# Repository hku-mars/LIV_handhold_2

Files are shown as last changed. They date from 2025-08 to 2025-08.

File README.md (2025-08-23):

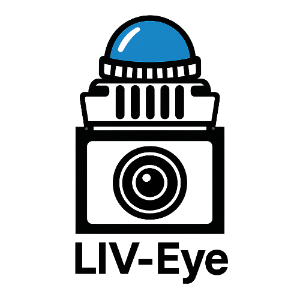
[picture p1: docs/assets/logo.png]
LIV-eye logo

<h1>LIV-Eye: A Low-Cost LiDAR-Inertial-Visual Fusion 3D Sensor for Robotics and Embodied AI <a href="./README_zh.md">[中文]</a></h1>

<p align="center">



</p>

---

## Table of Contents
- [Highlights](#highlights)
- [Repository Structure](#repository-structure)
- [Bill of Materials (BOM)](#bill-of-materials-bom)
- [Assembly](#assembly)
- [Wiring](#wiring)
- [Driver Installation and Run](#driver-installation-and-run)
- [LiDAR-Camera Joint Calibration](#lidar-camera-joint-calibration)
- [Running FAST-LIVO2](#running-fast-livo2)
- [Platform Adaptability](#platform-adaptability)
- [Acknowledgements](#acknowledgements)
- [License](#license)

---

## Highlights
> **One sentence summary**: A ~¥5000 (≈ $700) fully open-source hardware/software LiDAR-Inertial-Visual fusion perception kit. ⚙️ Easy assembly, no soldering, one-click reproducibility. 🐳 Supports ROS1/ROS2 and Docker, 🧭 full calibration workflow (intrinsic/extrinsic/time sync), 🧰 compatible with FAST-LIVO2 algorithms, and delivers colored point cloud and odometry results in just 5 minutes.

---

## Repository Structure
```text
├── FAST-LIVO2-Mid360-Config - The configuration and launch files of FAST-LIVO2 for the Mid-360 LiDAR
├── liv_eye_cad - Solidworks files for LIV-Eye
├── livox_ros_driver2 - Livox LiDAR ROS driver
├── mvs_ros_driver - Hikvision Camera ROS driver
└── README.md - Project homepage
└── ...
```

---

## Bill of Materials (BOM)

> Target total cost: ≈ ¥5,000 (≈ $700, subject to actual purchase)

| Category | Model/Name | Reference Price | Image |
|---|---|---|---|
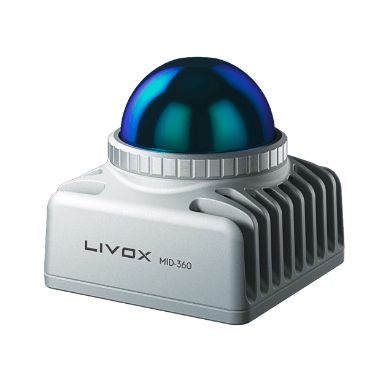
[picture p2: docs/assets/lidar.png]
MID-360
| LiDAR | [Livox Mid-360](https://www.livoxtech.com/cn/mid-360) | ¥3999 (≈ $560) |  |
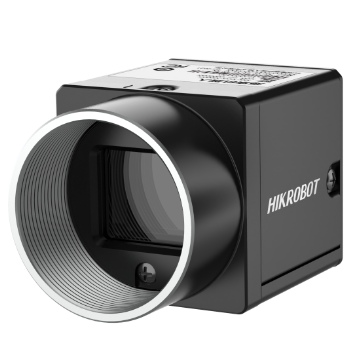
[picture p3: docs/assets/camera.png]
Camera
| Camera | [Hikvision MV-CU013-A0UC](https://www.hikrobotics.com/cn/machinevision/productdetail/?id=12628) | ¥700 (≈ $100) |  |
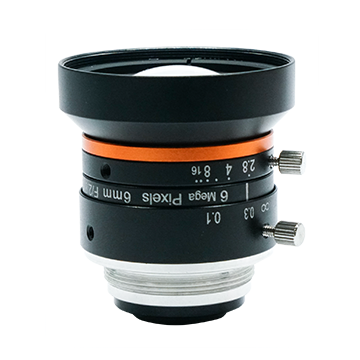
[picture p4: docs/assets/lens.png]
Lens
| Lens | [Hikvision MVL-HF0628M-6MPE](https://www.hikrobotics.com/en/machinevision/productdetail/?id=4871) | ¥150 (≈ $20) |  |
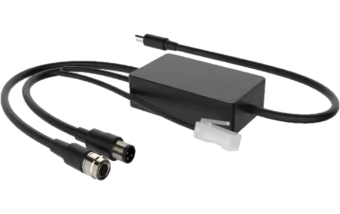
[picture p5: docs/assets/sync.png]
Sync
| Wire | [LiDAR-Camera Hardware Synchronizer](https://item.taobao.com/item.htm?id=842691502949) | ¥500 (≈ $70) |  |
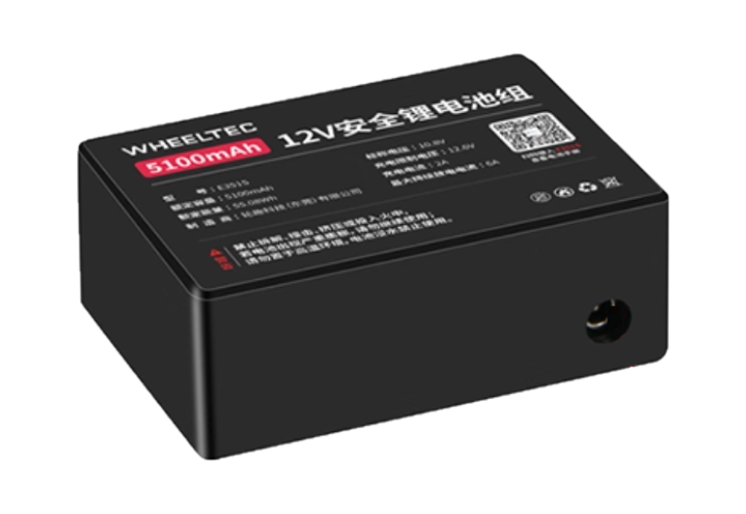
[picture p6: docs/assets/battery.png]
Battery
| Battery  | [12V DC Battery](https://detail.tmall.com/item.htm?id=657166348854) | ¥99 (≈ $15) |  |

---

## Assembly

Solidworks CAD files are provided in [liv_eye_cad](./liv_eye_cad).  
You can download and use them for 3D printing and assembly:

<p align="center">
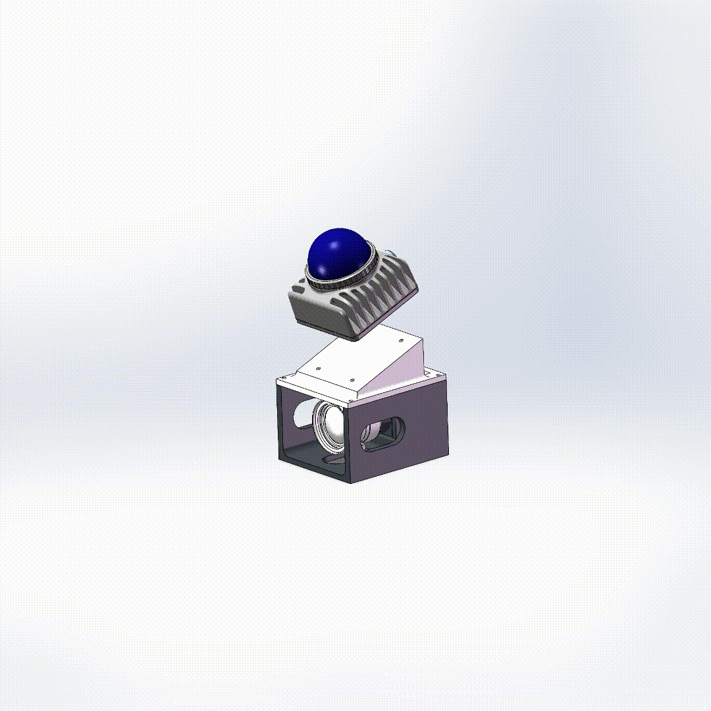
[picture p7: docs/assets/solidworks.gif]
Solidworks
  
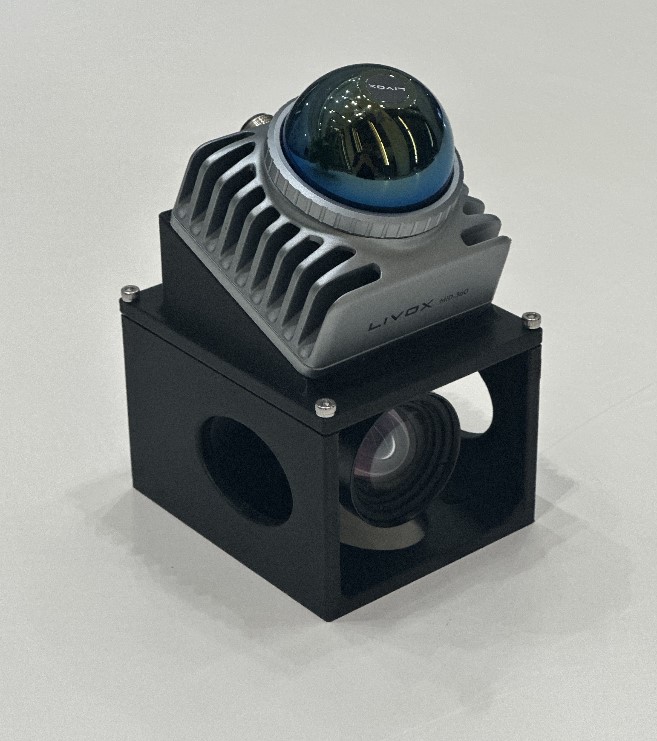
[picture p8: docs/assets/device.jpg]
Device
  
</p>

---

## Wiring

The diagram below shows the complete wiring of **LIV-Eye**, in just six steps:

<p align="center">
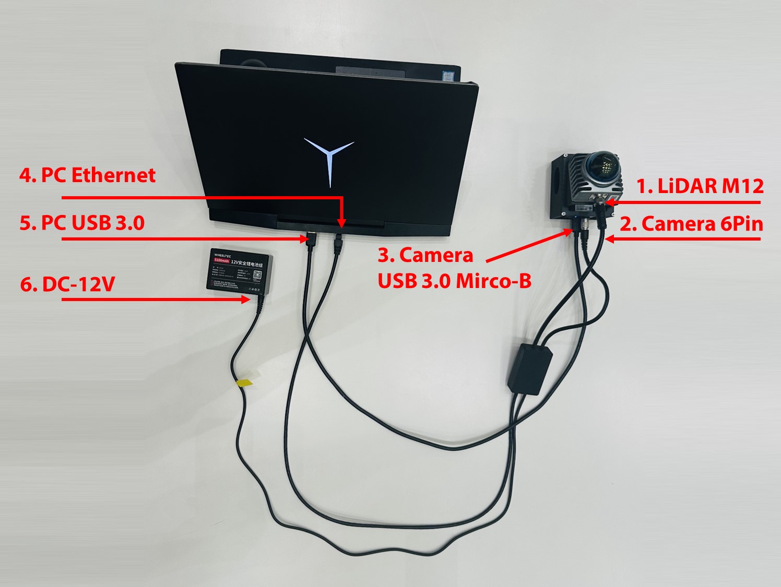
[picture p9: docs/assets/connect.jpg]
Wiring diagram
  
</p>

> **Note**  
> If you do not need to use the LiDAR-Camera hardware synchronizer, please refer to the connection method and STM32 hardware synchronization solution in [LIV_handhold](https://github.com/xuankuzcr/LIV_handhold).

---

## Driver Installation and Run

1. Download and install [MVS](https://connecthkuhk-my.sharepoint.com/:u:/g/personal/zhengcr_connect_hku_hk/Ed0Xq17d6udNqYn4vkR71bQBFz0z6_Kru3cz1gD95FIgrQ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) and [Livox-SDK2](https://github.com/Livox-SDK/Livox-SDK2). Set the camera to *trigger mode* in MVS.

2. Install the camera ROS driver [mvs_ros_driver](./mvs_ros_driver) and launch in trigger mode:
```bash
roslaunch mvs_ros_driver mvs_camera_trigger.launch 
```

3. Install and launch the LiDAR ROS driver [livox_ros_driver2](./livox_ros_driver2):
```bash
roslaunch livox_ros_driver2 msg_MID360.launch
```

4. Record sensor data:
```bash
rosbag record /livox/lidar /livox/imu /left_camera/image
```

> **Note**  
> The [mvs_ros_driver](./mvs_ros_driver) and [livox_ros_driver2](./livox_ros_driver2) are the same as those in [LIV_handhold](https://github.com/xuankuzcr/LIV_handhold), and include modifications to support millisecond-level hardware synchronization.

---

## LiDAR-Camera Joint Calibration

1. Calibrate camera intrinsics. e.g. [matlab](https://ustc-flicar.github.io/calibration/index#cameras).
2. Use [FAST-Calib](https://github.com/hku-mars/FAST-Calib) for LiDAR–camera extrinsic calibration.

<p align="center">
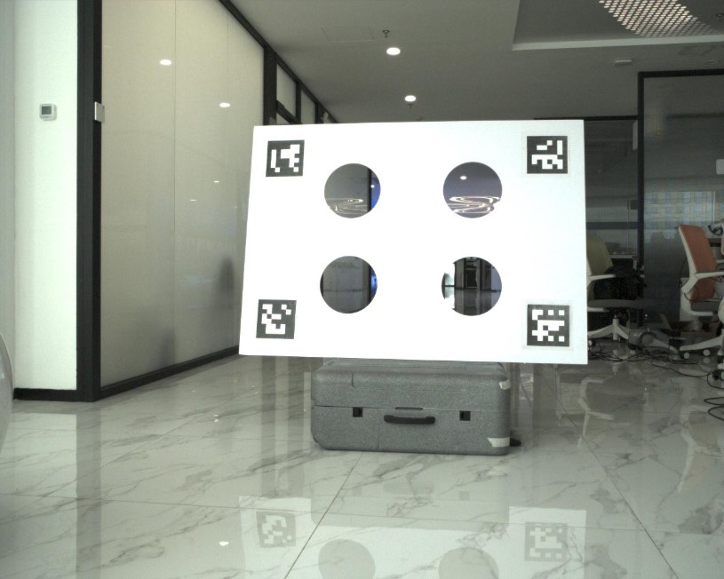
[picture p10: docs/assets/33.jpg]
camera calibration
  
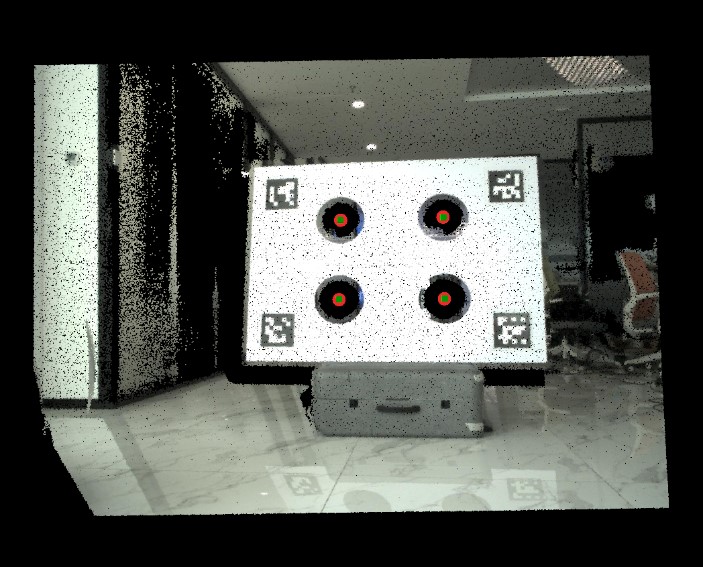
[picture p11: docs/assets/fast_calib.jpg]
fast calib
  
</p>

---

## Running FAST-LIVO2

Install [FAST-LIVO2](https://github.com/hku-mars/FAST-LIVO2). The configuration and launch files for the Mid-360 are provided in [FAST-LIVO2-Mid360-Config](./FAST-LIVO2-Mid360-Config). Update the intrinsic and extrinsic parameters to match your device, then run:
```bash
roslaunch fast_livo mapping_mid360.launch
```

This demo corresponds to the example LIV-Eye rosbag, which can be downloaded [here](https://pan.baidu.com/s/1bs9hSF9BD0LZFTiiEkNLeg?pwd=2zr5).
<p align="center">
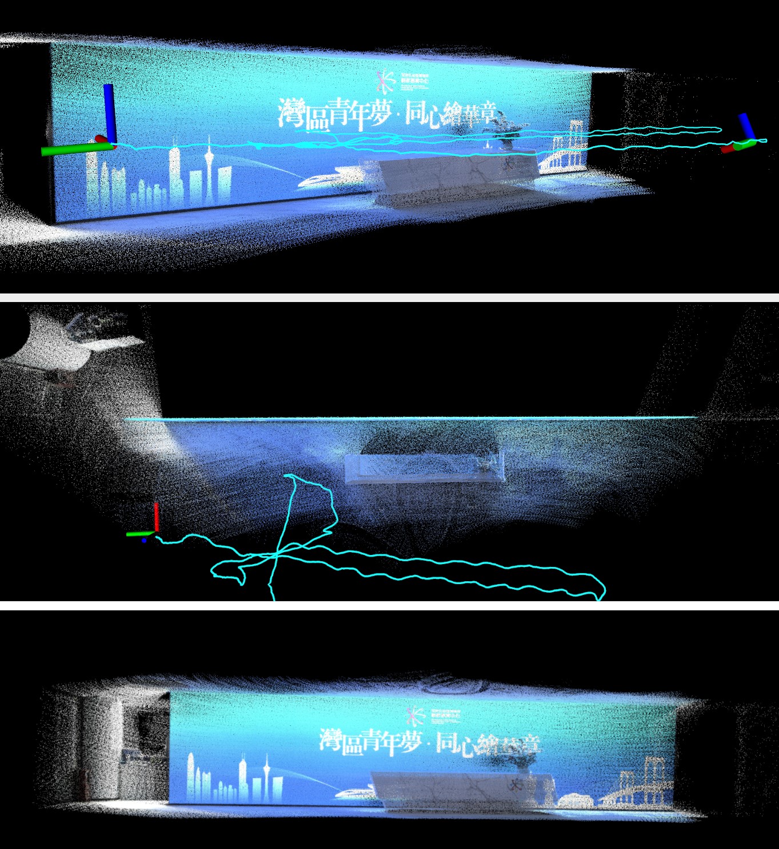
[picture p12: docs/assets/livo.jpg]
livo2 results
  
</p>

---

## Platform Adaptability

**LIV-Eye is compact yet versatile!** With its small form factor, standardized wiring, and open-source software, it can be seamlessly integrated into a wide range of robotic platforms to enable perception, navigation, and embodied AI research.

<p align="center">
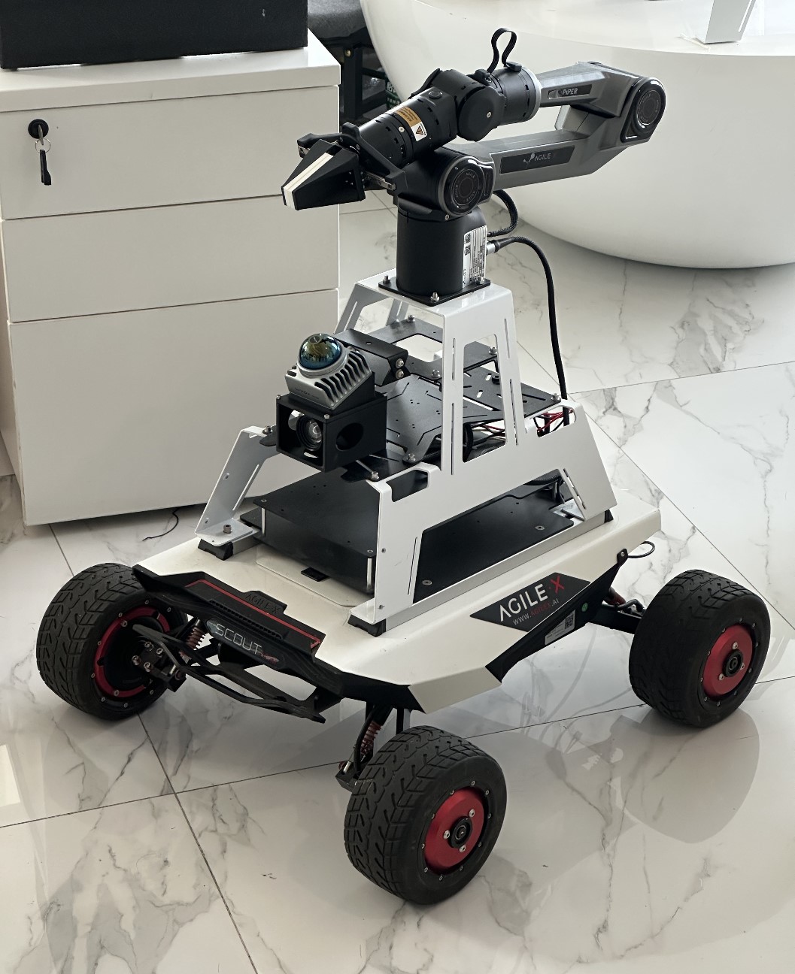
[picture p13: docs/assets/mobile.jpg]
LIV-Eye on wheeled robot
  
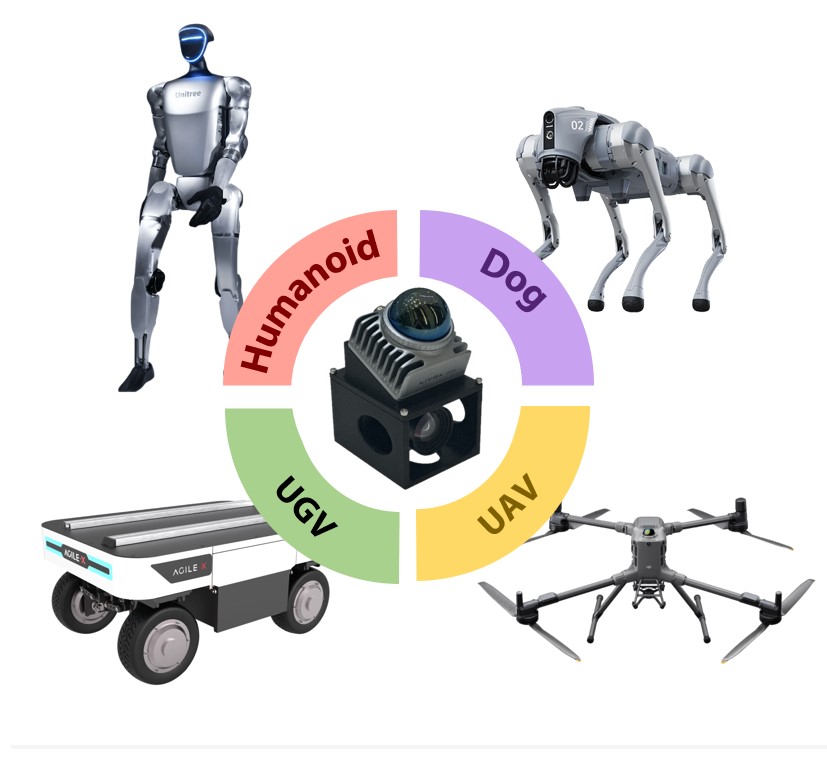
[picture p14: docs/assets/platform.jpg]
  
</p>

## Acknowledgements

This project is based on the following open-source projects:  

- Driver and time synchronization: [LIV_handhold](https://github.com/xuankuzcr/LIV_handhold)  
- Calibration method: [FAST-Calib](https://github.com/hku-mars/FAST-Calib)  
- Algorithm: [FAST-LIVO2](https://github.com/hku-mars/FAST-LIVO2)  
- CAD Design: [Link](https://github.com/hku-mars/FAST-LIVO2/issues/119) by [pcl5](https://github.com/pcl5)
---

## License

The source code is released under the GPLv2 license.  

If you use this codebase in academic research, please cite any of the following papers:

```
[1] Zheng, Chunran, et al. "FAST-LIVO2: Fast, Direct LiDAR-Inertial-Visual Odometry." 
[2] Zheng, Chunran, et al. "FAST-LIVO: Fast and Tightly-coupled Sparse-Direct LiDAR-Inertial-Visual Odometry." 
[3] Zheng, Chunran, et al. "FAST-Calib: LiDAR-Camera Extrinsic Calibration in One Second." 
[4] Ziming, Wang, et al. "USTC FLICAR: A sensors fusion dataset of LiDAR-inertial-camera for heavy-duty autonomous aerial work robots." 
```

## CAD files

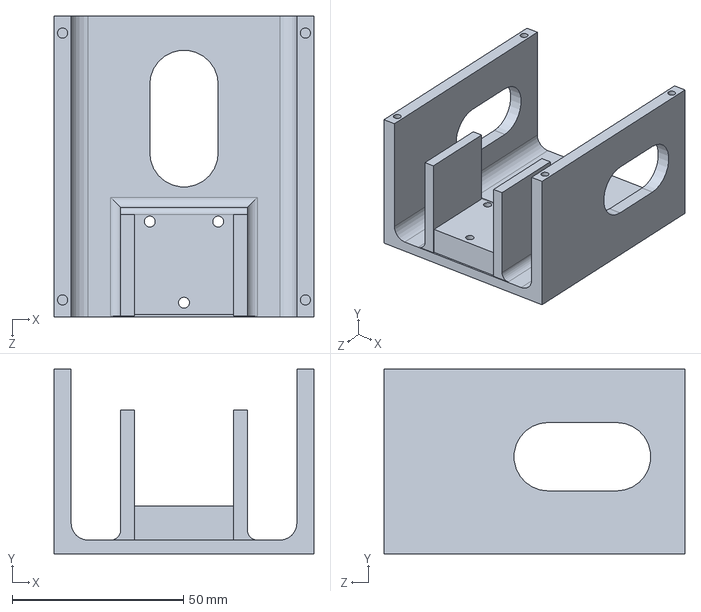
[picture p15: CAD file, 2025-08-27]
liv_eye_cad/camera_raw.SLDPRT
76.0 x 54.0 x 88.0 mm

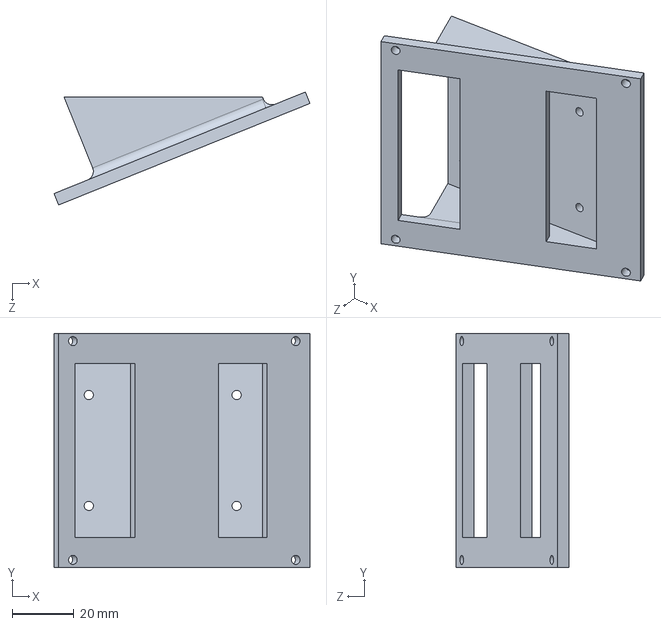
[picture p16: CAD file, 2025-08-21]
liv_eye_cad/mid_raw.SLDPRT
83.1 x 76.0 x 36.7 mm

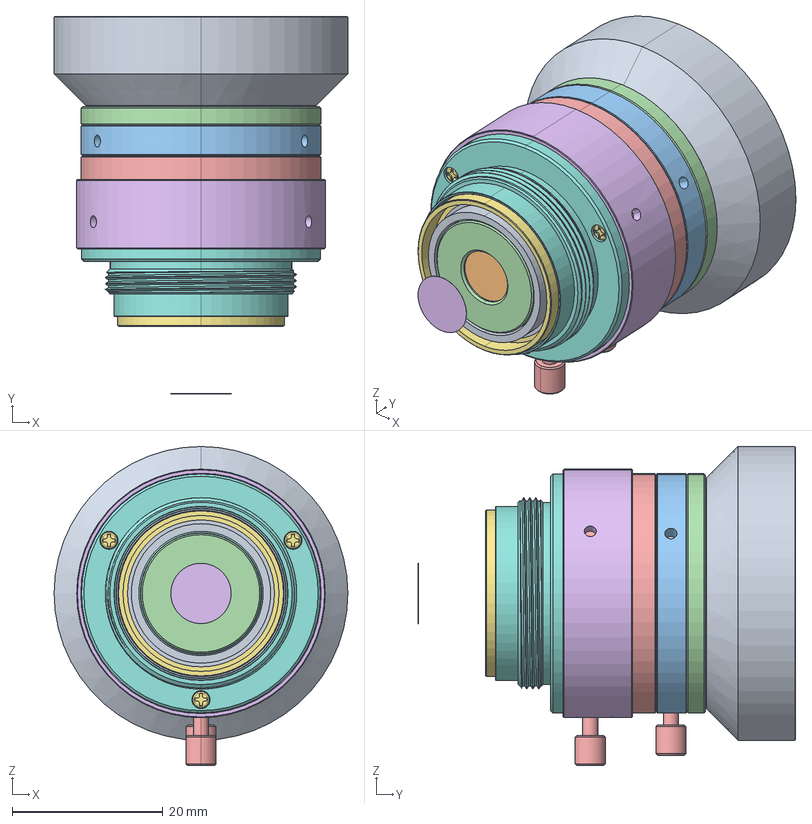
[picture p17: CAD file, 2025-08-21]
liv_eye_cad/MVL-HF0628M-6MPE.stp
39.0 x 50.1 x 42.3 mm
MVL-HF0628M-6MPE-201_7_1
MVL-HF0628M-6MPE-101_6_1
MVL-HF0628M-6MPE-301_6_1
MVL-HF0628M-6MPE-308_9_1
MVL-HF0628M-6MPE-202_4_1
MVL-HF0628M-6MPE403_6_1
MVL-HF0628M-6MPE-401_4_1
MVL-HF0628M-6MPE-109_16_1
MVL-HF0628M-6MPE-G1_2_1
MVL-HF0628M-6MPE-G9_2_1
MVL-HF0628M-6MPE-102_1_1
MVL-HF0628M-6MPE-108_8_1
MVL-HF0628M-6MPE-501_2_1_2 x 2
MVL-HF0628M-6MPE-XM_1_1
MVL-HF0628M-6MPE-502_6_1_2 x 3
MVL-HF0628M-6MPE-203_23_1_2

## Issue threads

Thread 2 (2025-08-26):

Where to buy LiDAR-Camera Hardware Synchronizer?

NamDinhRobotics, 2025-08-26:
Thanks for your great work!
I can not find the link to buy the connector.
Could you share the link to buy the LiDAR-Camera Hardware Synchronizer? ( on AliExpress or an international website)

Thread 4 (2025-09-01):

Solidworks CAD files install issue

Internationcode, 2025-09-01:
Hello, may I ask which mount can be directly installed on the Unitree Go2 robot dog?

ustc-flicar, 2025-09-01:
Hello, you may refer to this solution, which uses a square fixture mounted on the quadruped robot to secure the LIV-Eye. I believe there could be an even more elegant connection approach, which could be further explored in the design.

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

Internationcode, 2025-09-02:
Thank you very much for your reply. I’d like to ask if the CAD file of the square fixture is available. If it’s convenient, we could also connect via WeChat for further discussion. Here is my WeChat ID: qzwqbdjqqrasj

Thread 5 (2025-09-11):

关于非硬件同步下的相机驱动

JixinGao, 2025-09-11:
Hi，非常感谢开源与分享！
由于工作还涉及其它的传感器，我暂时无法使用硬件来同步LiDAR和相机，我查看相机的驱动lauch中只有外部触发和多相机的launch文件，想咨询一下是否可以基于ros系统时间来驱动mvs相机，或者需要在现有仓库的相机驱动中修改什么嘛？
感谢！

ustc-flicar, 2025-09-14:
您好，感谢关注，建议还是使用带有硬件触发的方案，并采用仓库中的驱动，这样运行FAST-LIVO2的效果最好

JixinGao, 2025-09-14:
感谢回复与建议！我尝试一下

Closed 2025-09-14.

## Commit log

2025-08-21 [Init] initialize the repository.
    [MVL-HF0628M-6MPE.stp, camera_raw.SLDPRT, mid_raw.SLDPRT]
2025-08-21 [Fix] fix jump link of calibration
2025-08-21 [Add] Added sample rosbag download address.
2025-08-22 [Add] Acknowledgements of CAD Design.
2025-08-25 [Update] update the revised camera driver yaml.
2025-08-27 [Fix] Increase the size of the hole appropriately to cope with possible shrinkage in 3D printing
    [camera_raw.SLDPRT]
2025-08-29 [Fix] fixed Mid-360 LiDAR to IMU extrinsic_T.

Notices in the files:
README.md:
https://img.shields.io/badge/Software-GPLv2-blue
